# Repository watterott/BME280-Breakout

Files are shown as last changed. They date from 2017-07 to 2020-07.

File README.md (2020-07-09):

# BME280-Breakout
Breakout with BME280 Digital Environmental Sensor from Bosch Sensortec.

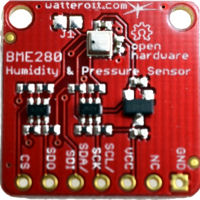
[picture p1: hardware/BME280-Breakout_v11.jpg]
BME280-Breakout


* [Bosch BME280](https://www.bosch-sensortec.com/en/bst/products/all_products/bme280) Integrated Environmental Sensor (Humidity, Pressure and Temperature)
* Temperature Sensor -40...85°C
* Pressure Sensor 300...1100hPa (+9000...-500m above/below sea level)
* Humidity Sensor 0...100%
* On-board 3.3V voltage regulator
* SPI Interface (up to 10MHz)
* TWI/I2C Interface (address 0x76 when SDO=0 or 0x77 when SDO=1, CS=1 for I2C)
* 3.3V - 5V Power Supply and Logic Level
* Open-Source and released under the [Creative Commons Attribution Share-Alike License](https://creativecommons.org/licenses/by-sa/4.0/).
* **[Documentation on learn.watterott.com](https://learn.watterott.com)**

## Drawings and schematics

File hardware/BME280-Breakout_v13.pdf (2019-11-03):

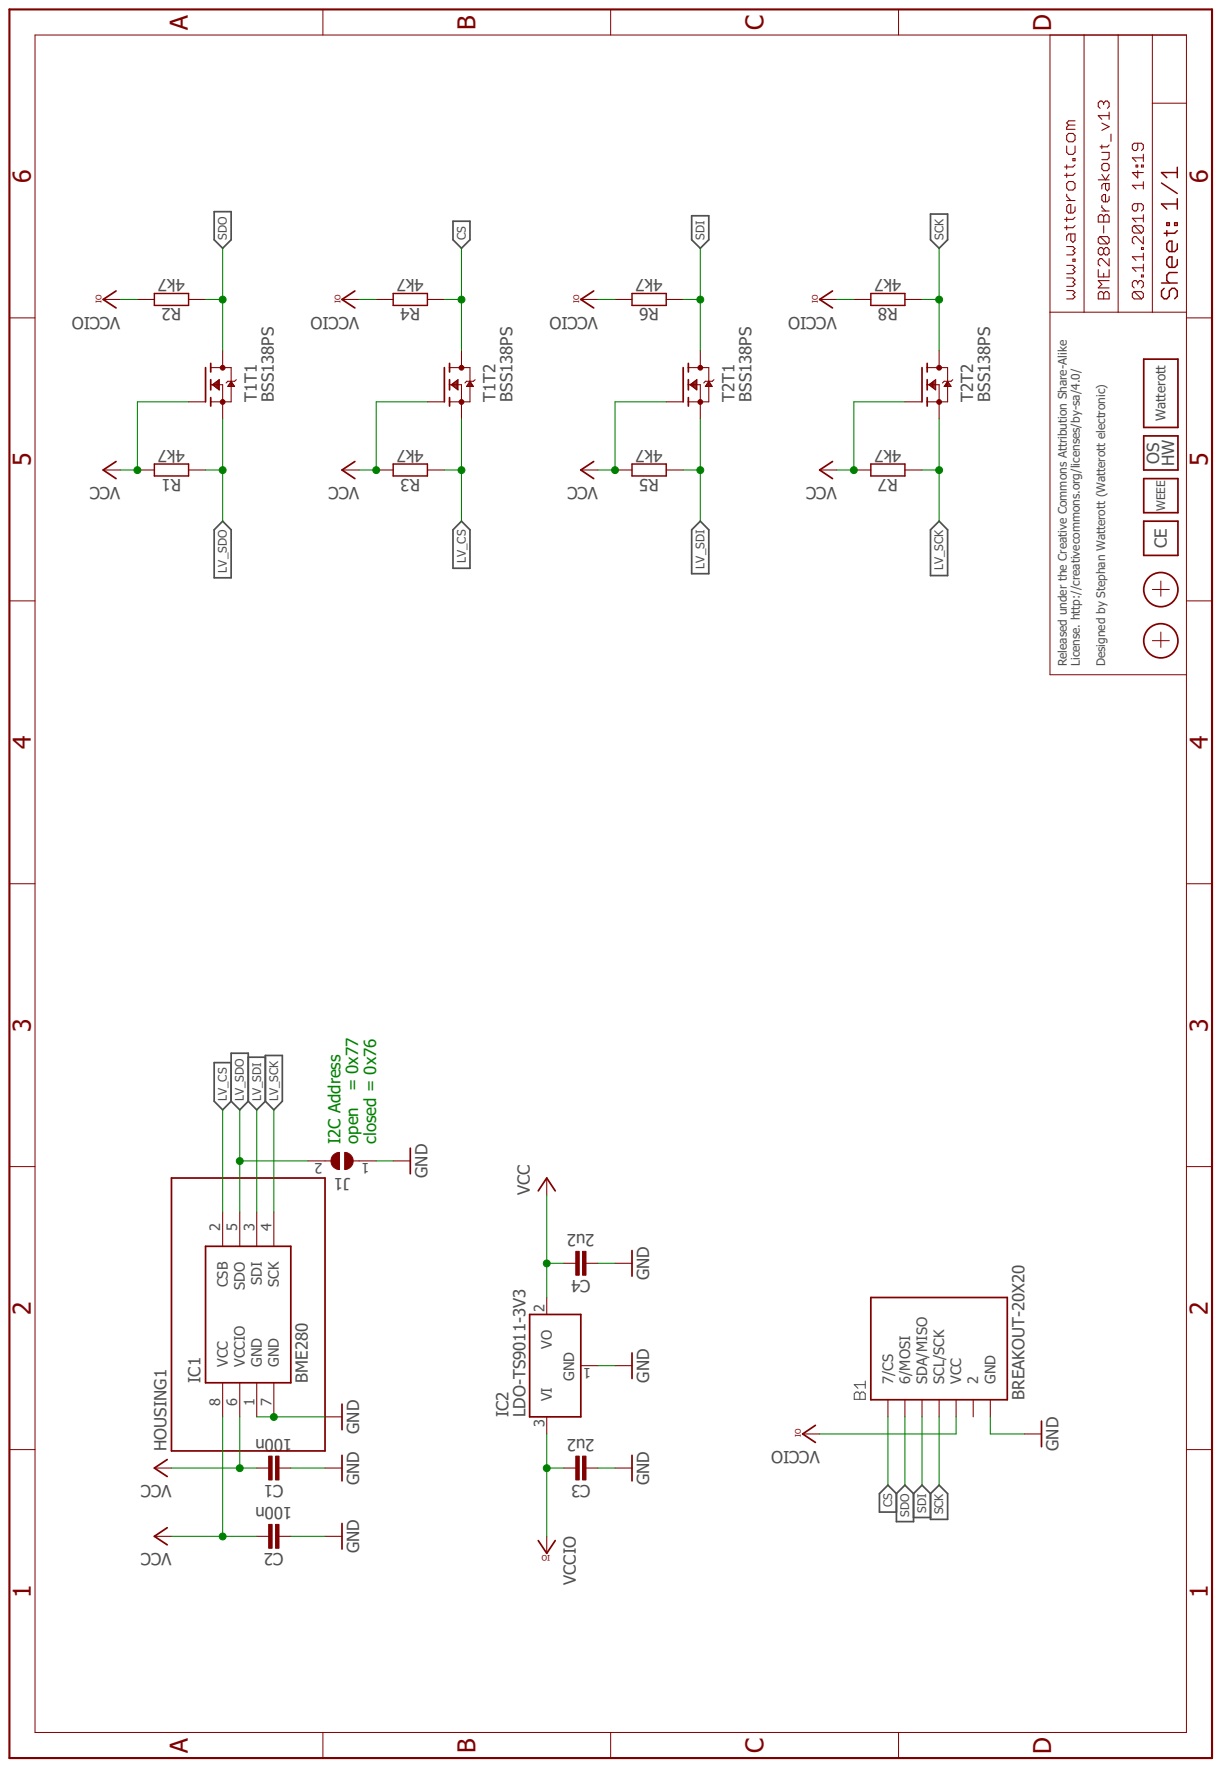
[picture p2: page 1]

Released under the Creative Commons Attribution Share-Alike

License. http://creativecommons.org/licenses/by-sa/4.0/ Designed by Stephan Watterott (Watterott electronic) BREAKOUT-20X20

CE WEEE Watterott OS HW

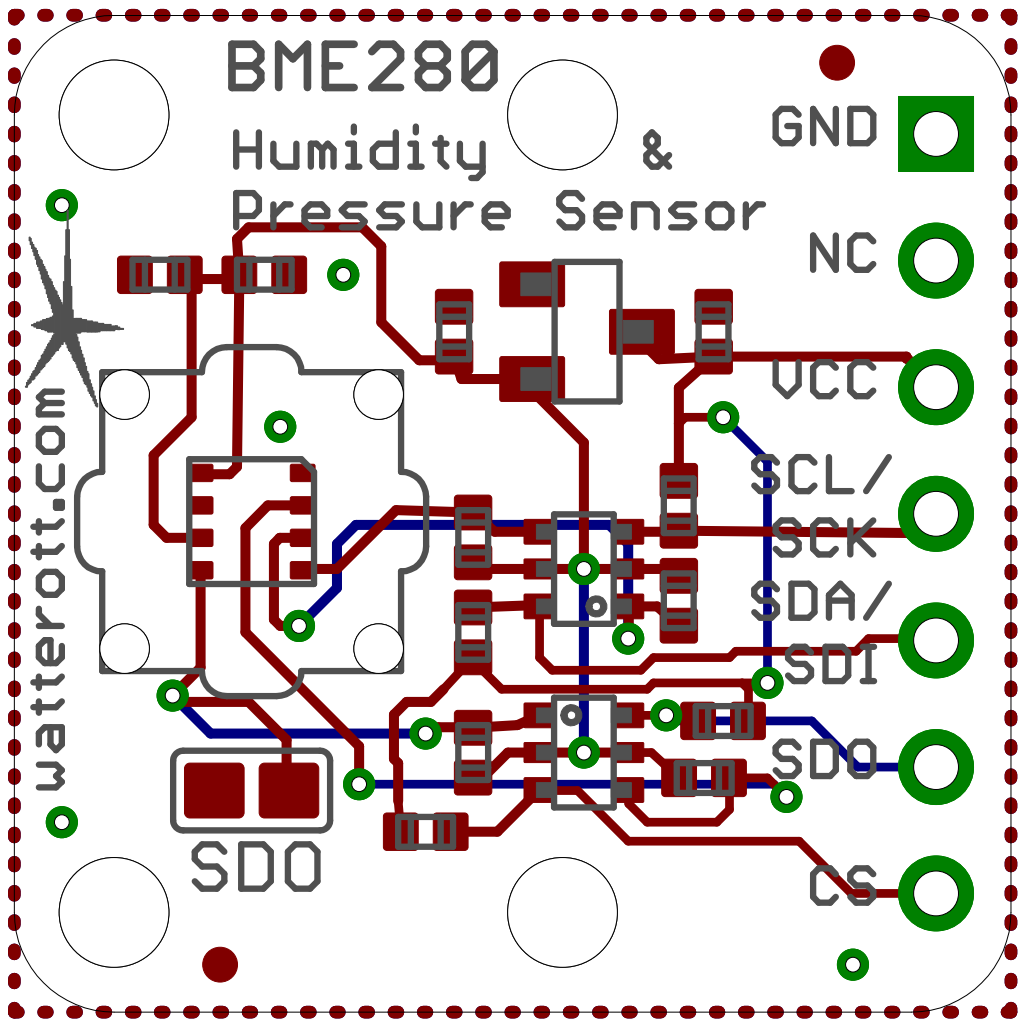
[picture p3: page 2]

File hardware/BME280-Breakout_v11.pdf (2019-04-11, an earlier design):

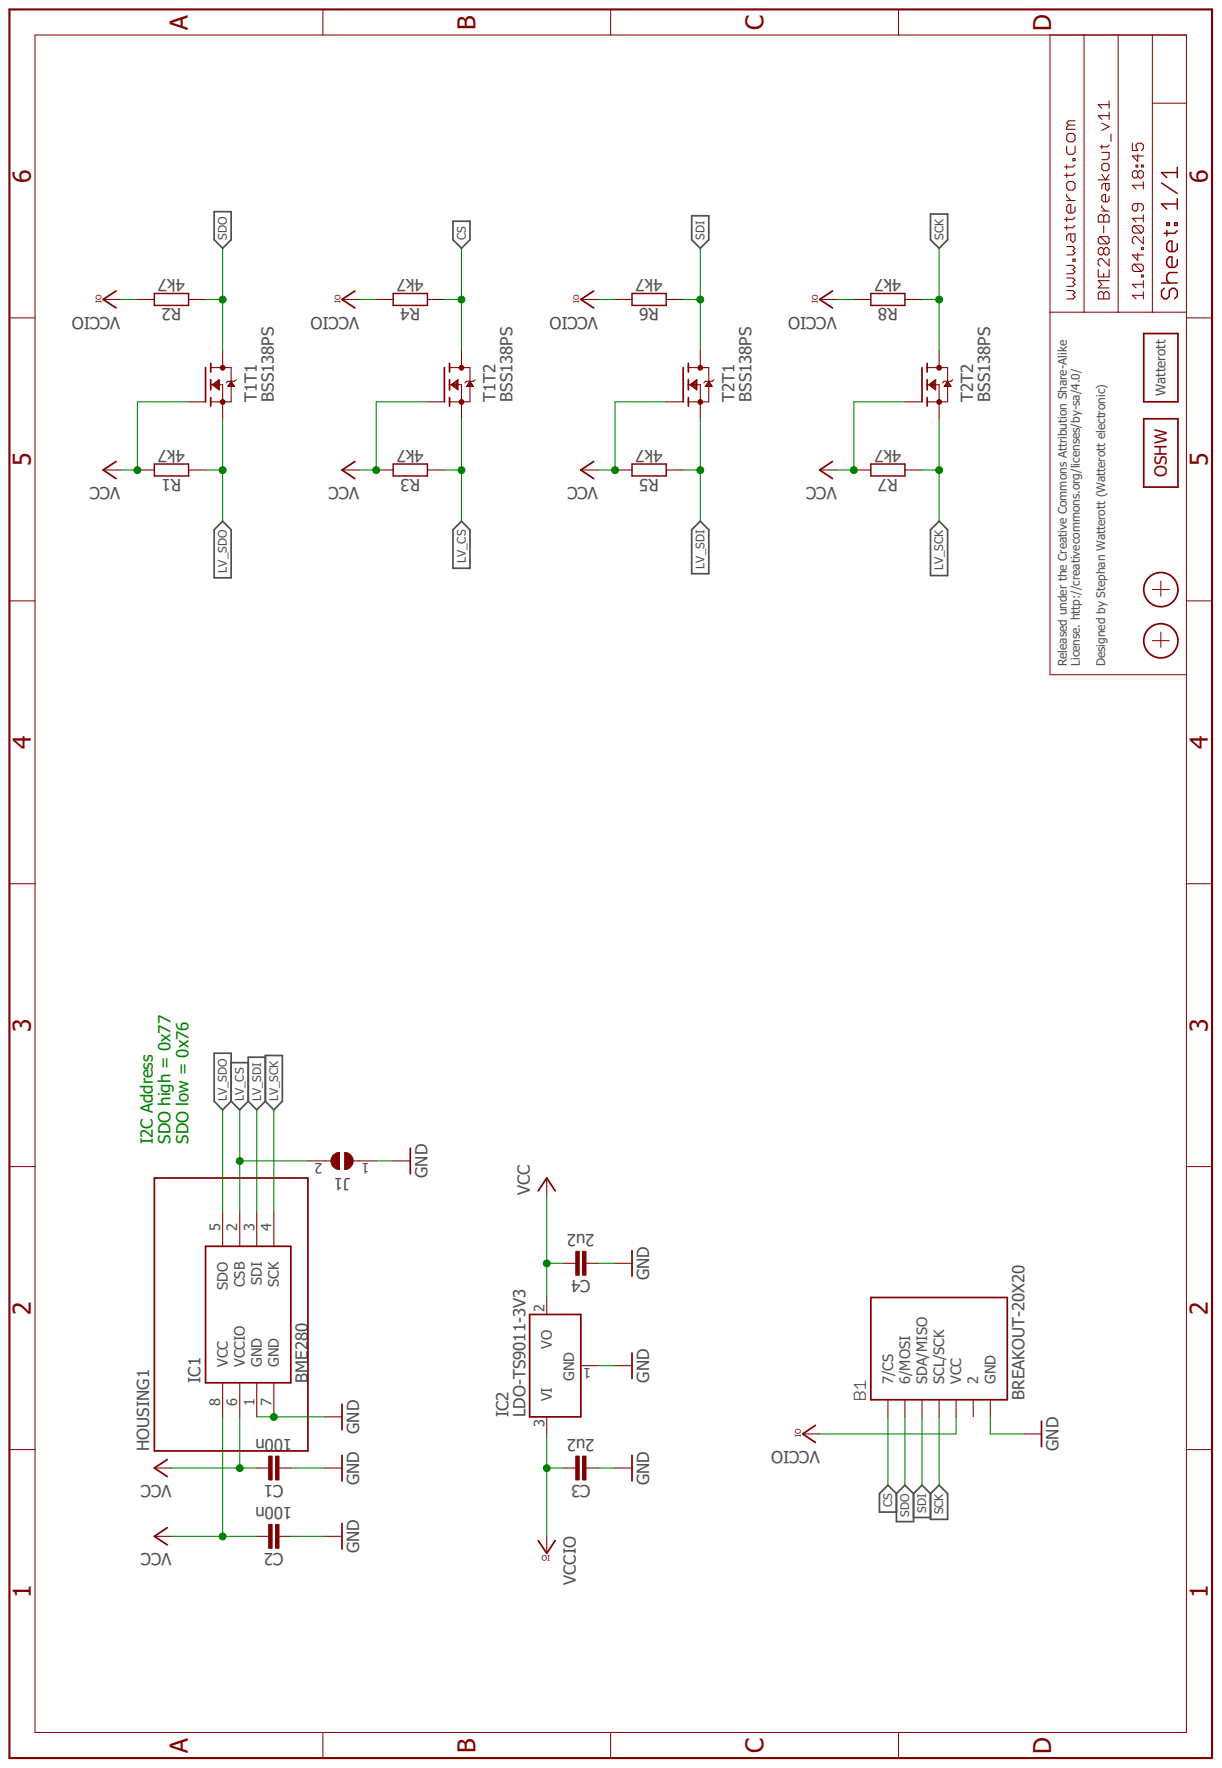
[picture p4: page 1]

Released under the Creative Commons Attribution Share-Alike

License. http://creativecommons.org/licenses/by-sa/4.0/ Designed by Stephan Watterott (Watterott electronic) BREAKOUT-20X20

I2C Address SDO high = 0x77 SDO low = 0x76

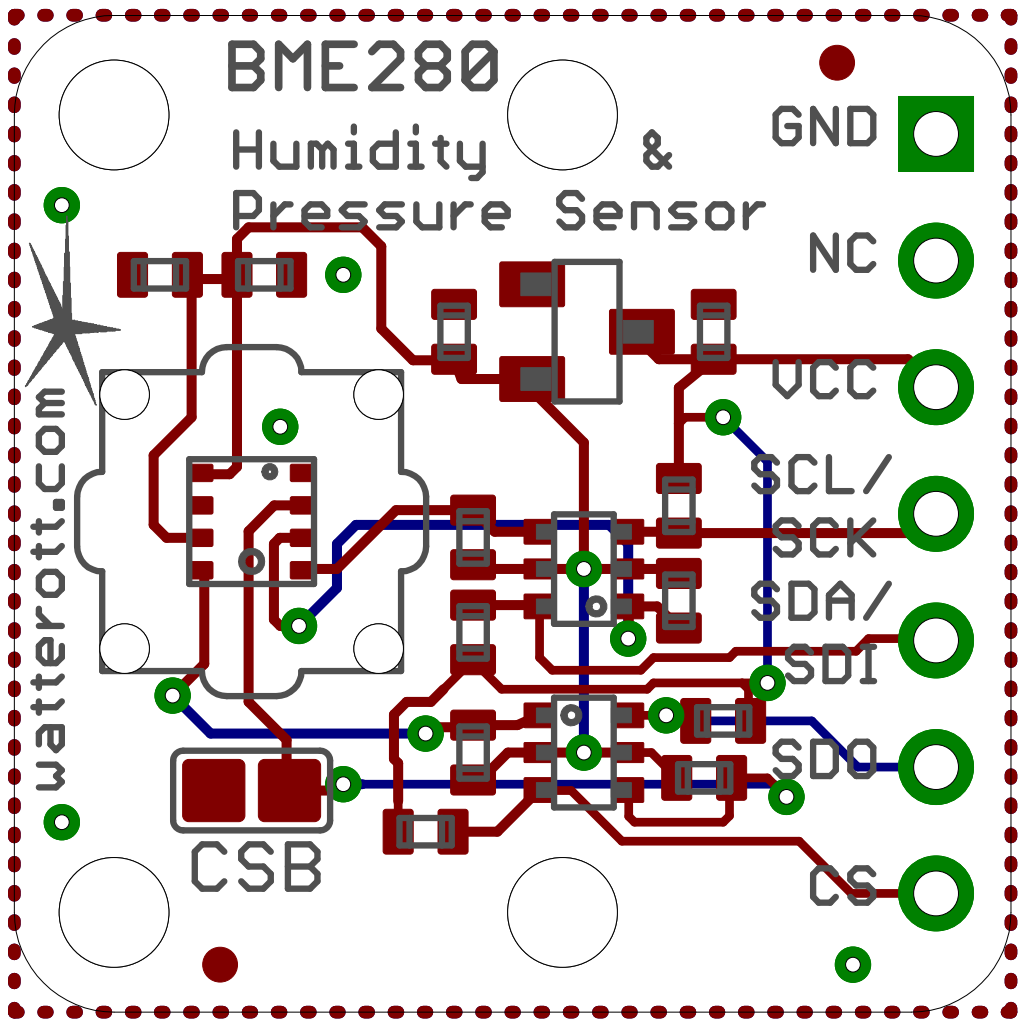
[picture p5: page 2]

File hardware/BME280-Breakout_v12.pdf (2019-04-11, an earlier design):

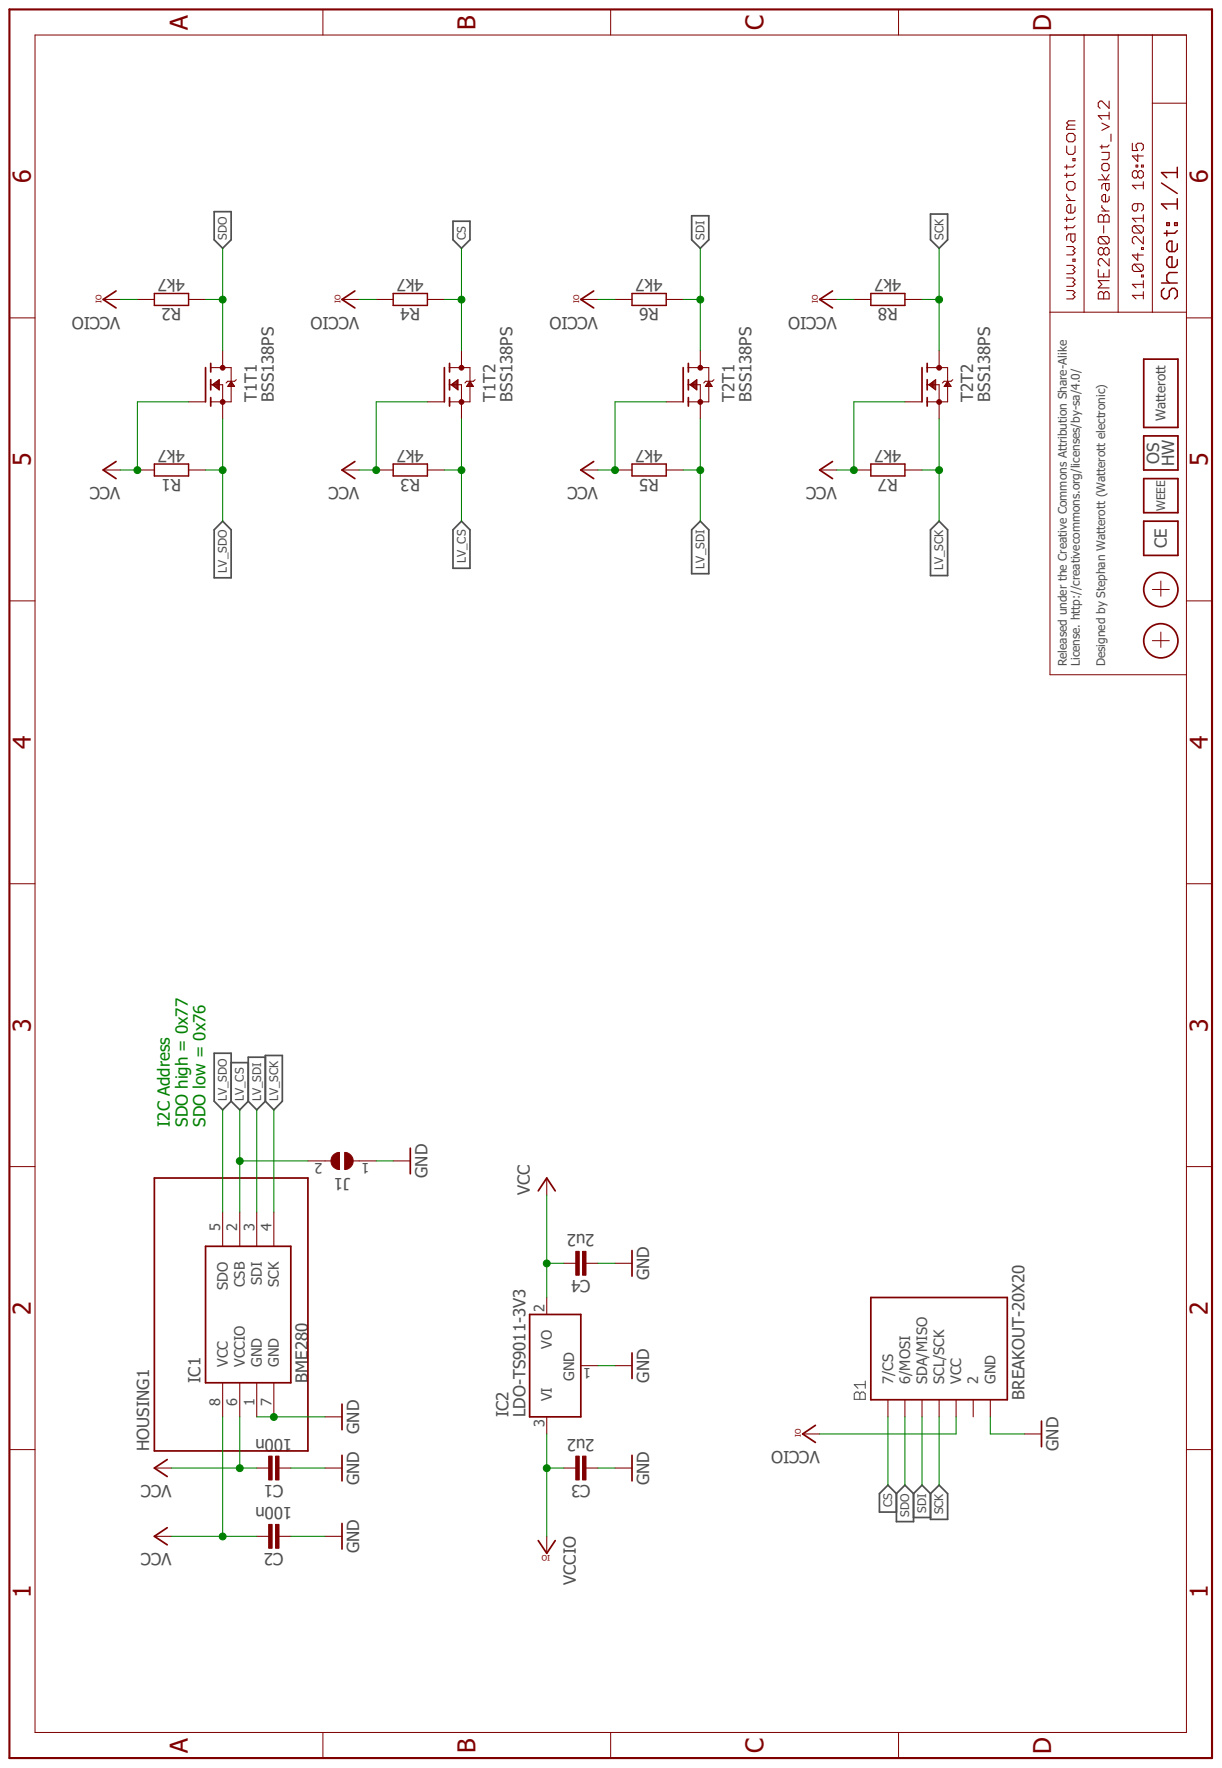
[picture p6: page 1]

Released under the Creative Commons Attribution Share-Alike

License. http://creativecommons.org/licenses/by-sa/4.0/ Designed by Stephan Watterott (Watterott electronic) BREAKOUT-20X20

CE WEEE Watterott OS HW

I2C Address SDO high = 0x77 SDO low = 0x76

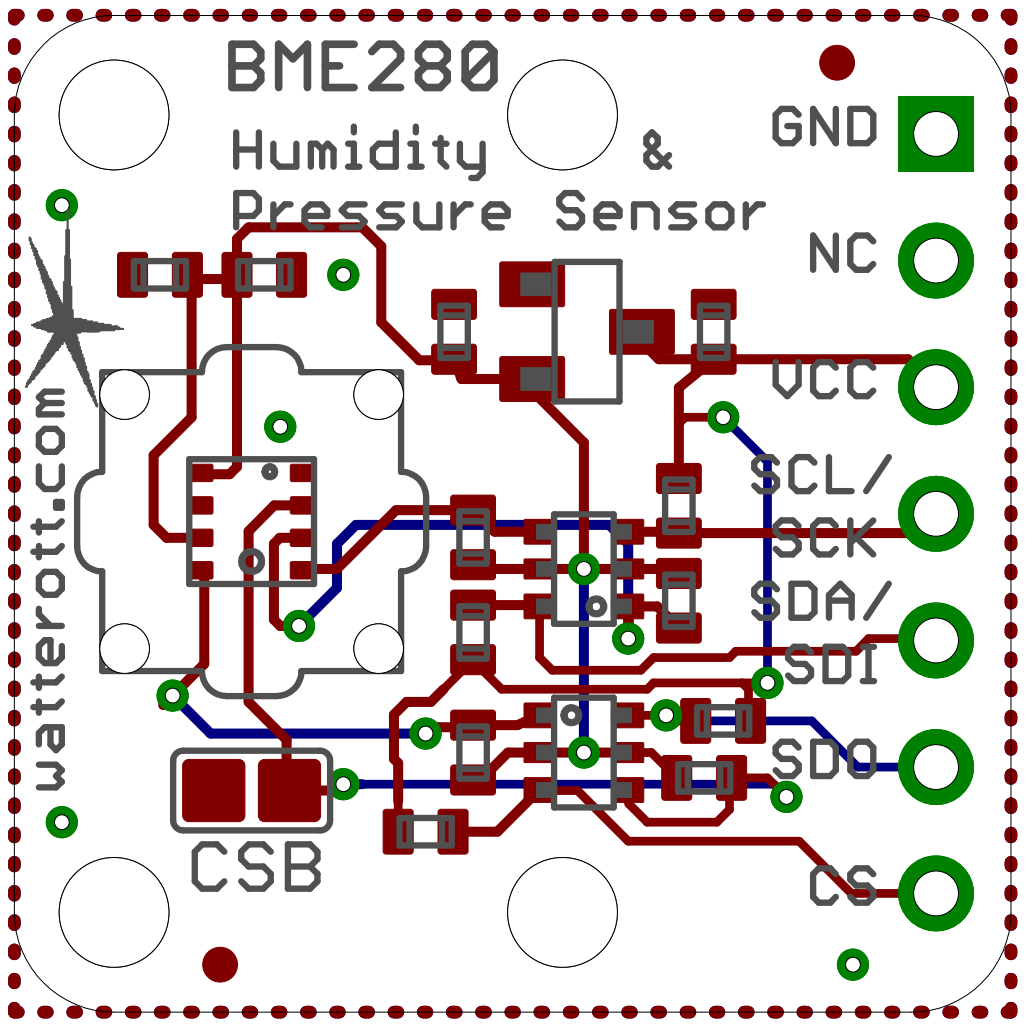
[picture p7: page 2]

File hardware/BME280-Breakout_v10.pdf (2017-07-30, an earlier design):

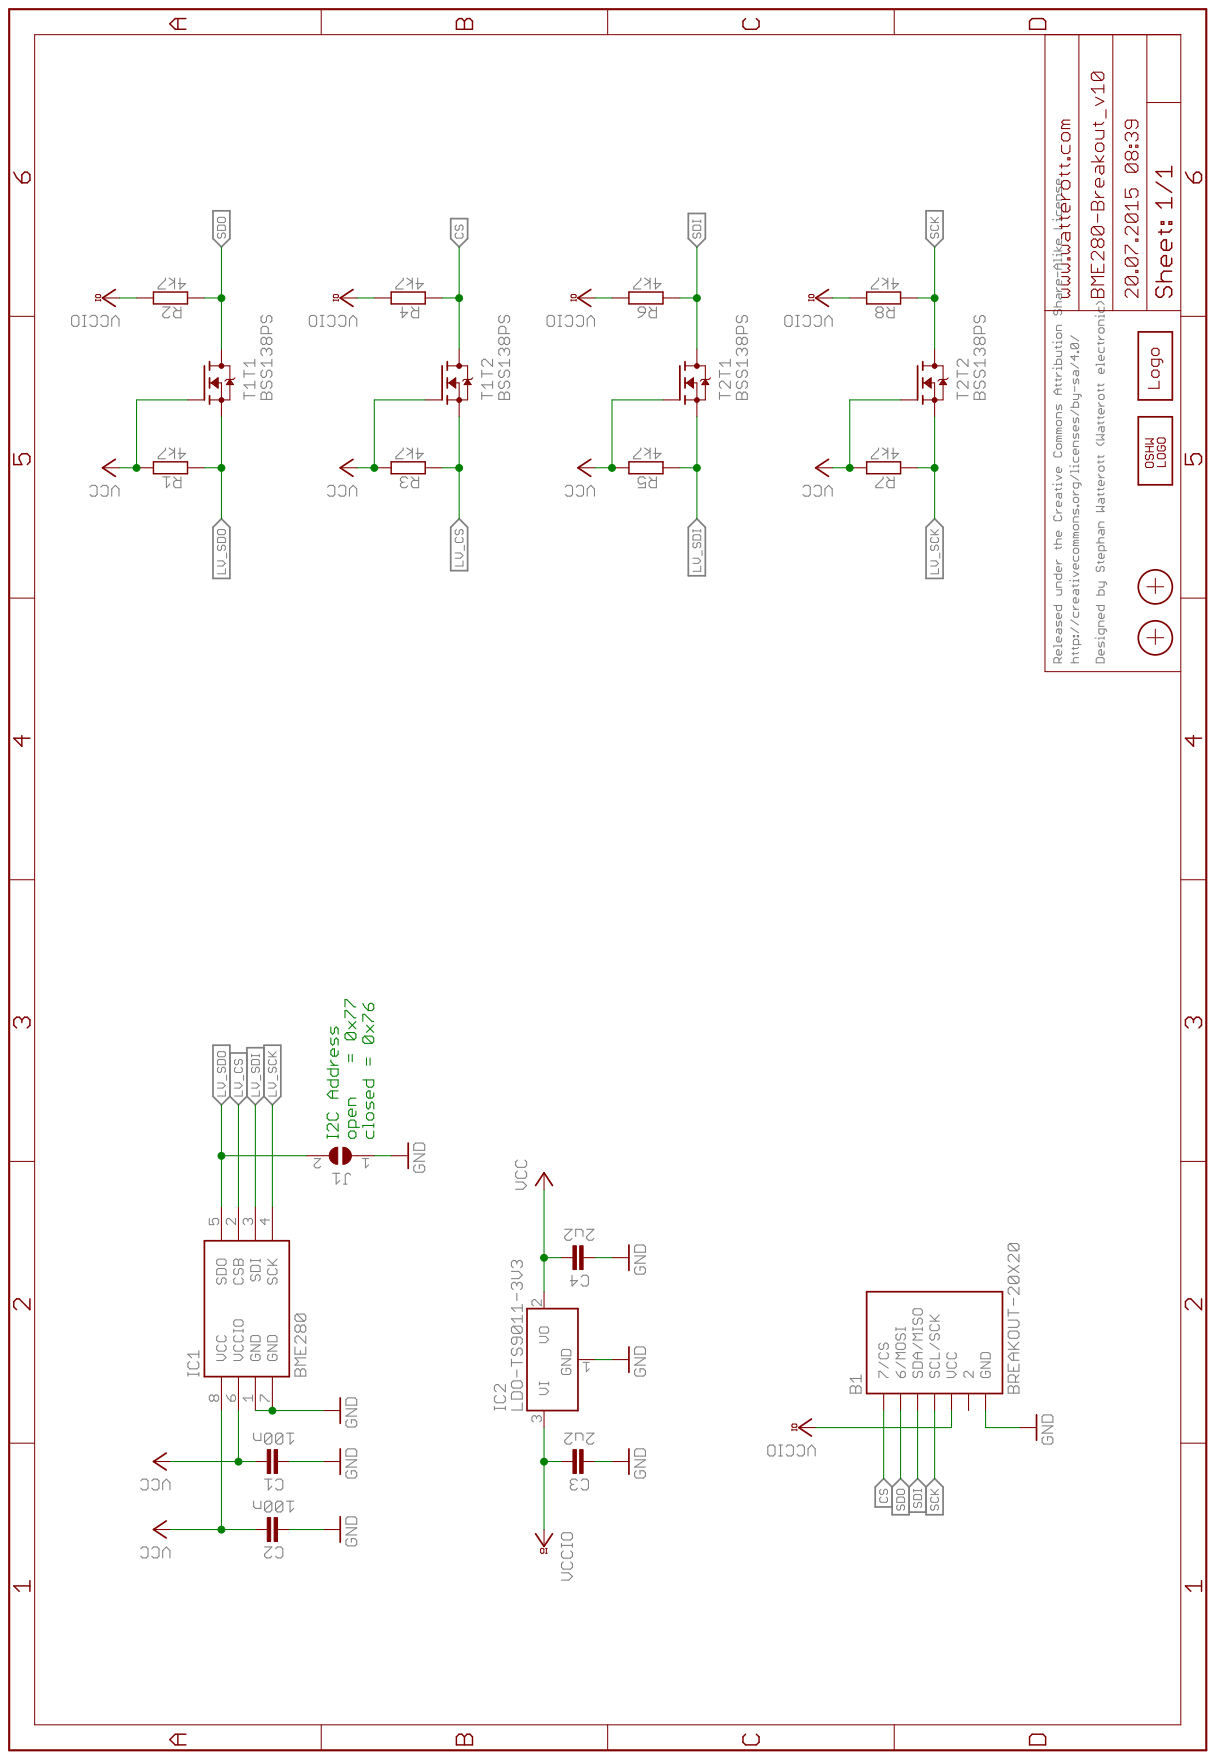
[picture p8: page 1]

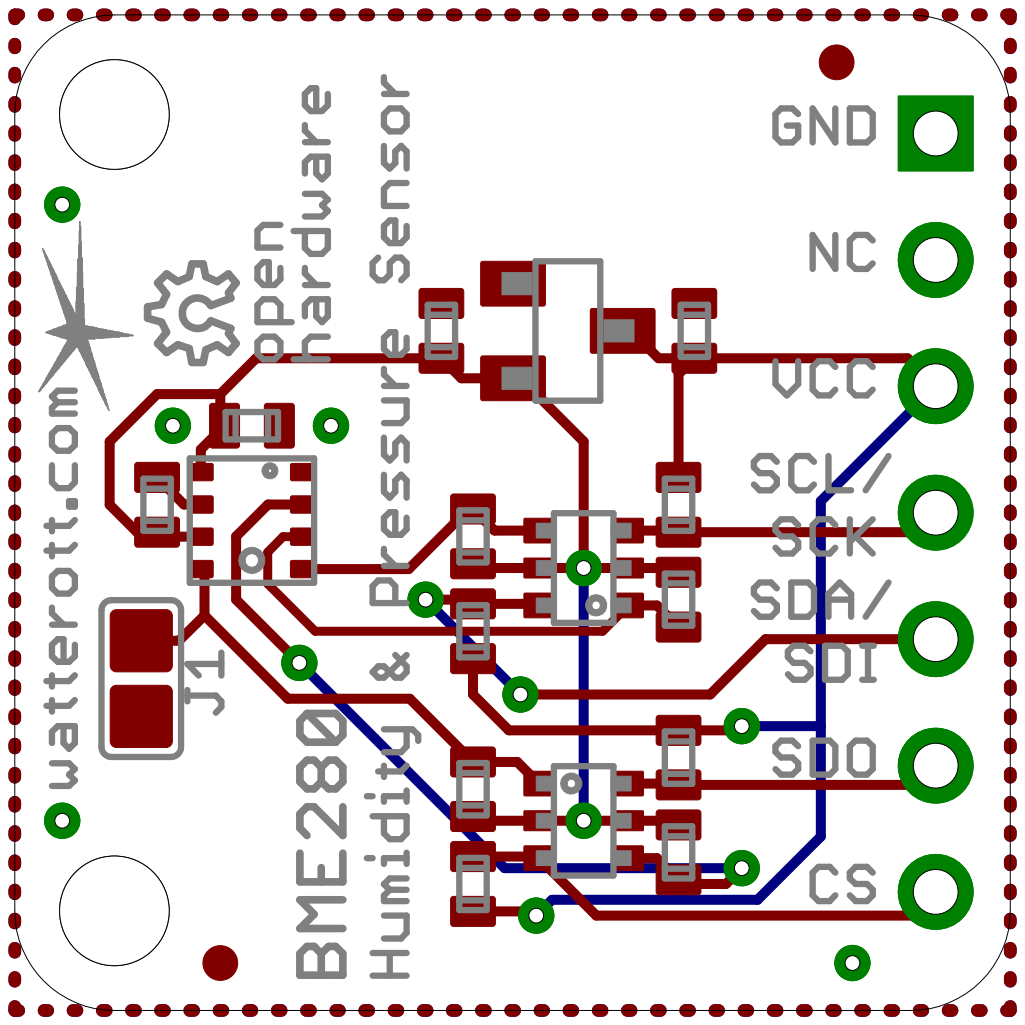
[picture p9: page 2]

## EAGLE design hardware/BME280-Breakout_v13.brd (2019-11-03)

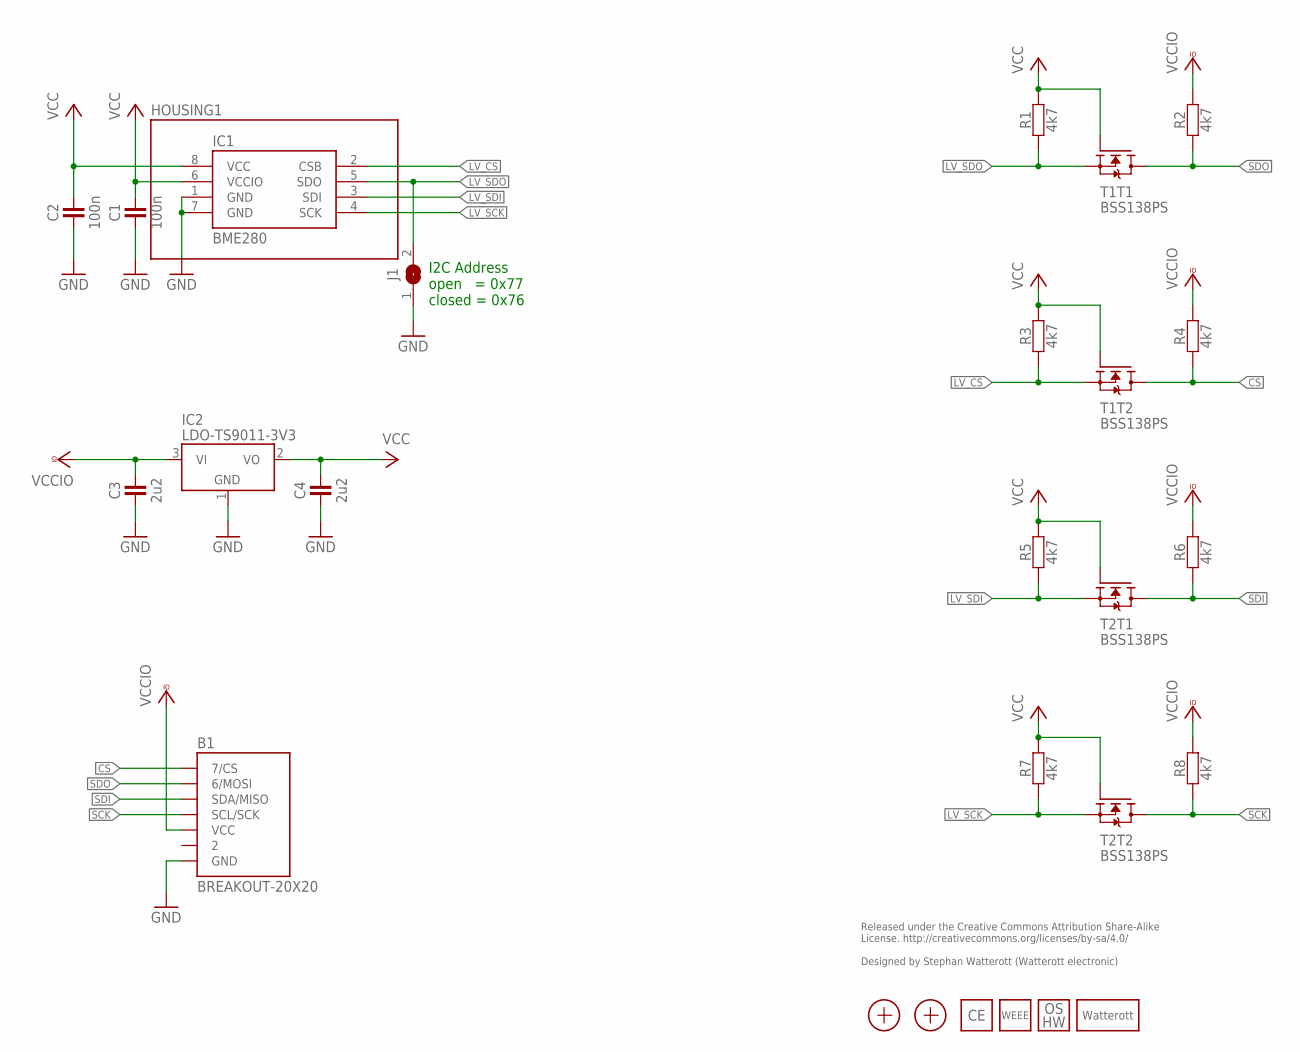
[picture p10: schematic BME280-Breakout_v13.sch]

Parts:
B1: BREAKOUT-20X20
C1, C2: 100n; C0402
C3, C4: 2u2; C0402
HOUSING1: SF2
IC1: BME280
IC2: LDO-TS9011-3V3; SOT23
J1: JUMPER2-0603
LOGO3: LOGO_CE-2; CE_2MM
LOGO4: LOGO_WEEE-4; WEEE_4MM
LOGO5: LOGO_SPARK-2; SPARK_2MM
LOGO6: LOGO_OSHW-2; OSHW_2MM
R1, R2, R3, R4, R5, R6, R7, R8: 4k7; C0402
T1, T2: BSS138PS; SOT363
X1, X2: PASSER-07; PASSER_07MM

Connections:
CS: B1.CS (7/CS), R4.1, T1.3 (D)
GND: B1.GND, C1.1, C2.1, C3.1, C4.1, IC1.1 (GND), IC1.7 (GND), IC2.1 (GND), J1.1
LV_CS: IC1.2 (CSB), R3.1, T1.4 (S)
LV_SCK: IC1.4 (SCK), R7.1, T2.4 (S)
LV_SDI: IC1.3 (SDI), R5.1, T2.1 (S)
LV_SDO: IC1.5 (SDO), J1.2, R1.1, T1.1 (S)
SCK: B1.SCL/SCK, R8.1, T2.3 (D)
SDI: B1.SDA/MISO, R6.1, T2.6 (D)
SDO: B1.MOSI (6/MOSI), R2.1, T1.6 (D)
VCC: C1.2, C2.2, C4.2, IC1.6 (VCCIO), IC1.8 (VCC), IC2.2 (VO), R1.2, R3.2, R5.2, R7.2, T1.2 (G), T1.5 (G), T2.2 (G), T2.5 (G)
VCCIO: B1.VCC, C3.2, IC2.3 (VI), R2.2, R4.2, R6.2, R8.2

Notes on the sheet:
I2C Address open = 0x77 closed = 0x76
Released under the Creative Commons Attribution Share-Alike License. http://creativecommons.org/licenses/by-sa/4.0/ Designed by Stephan Watterott (Watterott electronic)

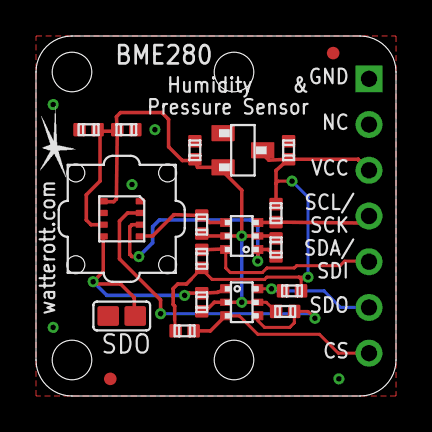
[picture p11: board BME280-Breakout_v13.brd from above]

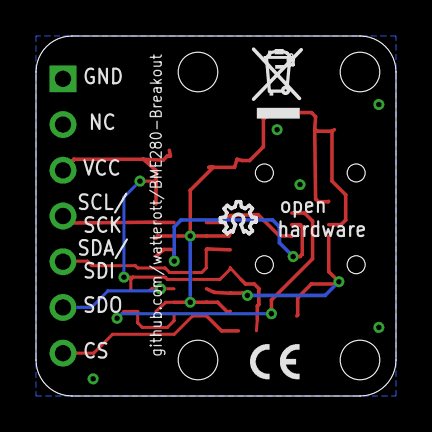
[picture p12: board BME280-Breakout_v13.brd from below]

Board: 2 copper layers, 20.0 x 20.0 mm, 25 parts (3 on the bottom side), 11 nets.

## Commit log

2018-05-01 added rev 1.1
    [BME280-Breakout_v11.brd, BME280-Breakout_v11.sch]
2018-09-27 updated schematics
    [BME280-Breakout_v11.brd, BME280-Breakout_v11.sch]
2018-09-27 added rev 1.2
    [BME280-Breakout_v12.brd, BME280-Breakout_v12.sch]
2019-11-03 added rev 1.3
    [BME280-Breakout_v13.brd, BME280-Breakout_v13.sch]
